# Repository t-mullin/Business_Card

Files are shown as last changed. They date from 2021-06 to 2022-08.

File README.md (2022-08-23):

# STG Business Card

## UPDATE!  
I am working on some updates to the STG Business Card project.
1. Adding additional options of form-factor/materials.
2. Adding Through-Hole and SMD versions.
3. Reworking of the project structure.

## Motive
The motive behind this project is to provide to prospective employers an example of my pcb work in a form factor that is easy for them to carry around. I came up with the idea of putting a simple Stepped Tone Generator onto a PCB the size of a business card after watching a video from [Look Mum No Computer](https://www.youtube.com/watch?v=4lK7kdgK7dI), where he builds an Atari Punk Console (Stepped Tone Generator). 

## PCB Design
Using the same instructables guide from [BrownDogGadgets](https://www.instructables.com/Build-an-Atari-Punk-circuit-on-a-breadboard/), I used KiCad to draw up the schematic and designed a PCB to go with it. The PCB is a 2-layer design with through-hole components. Below are pictures of the 3D model and the PCB layout in KiCad.   

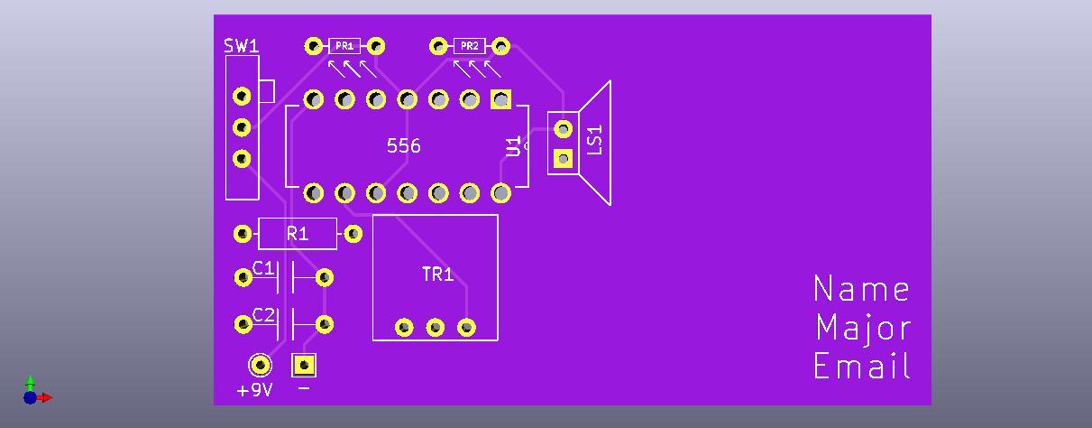
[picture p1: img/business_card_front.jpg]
Business Card Front


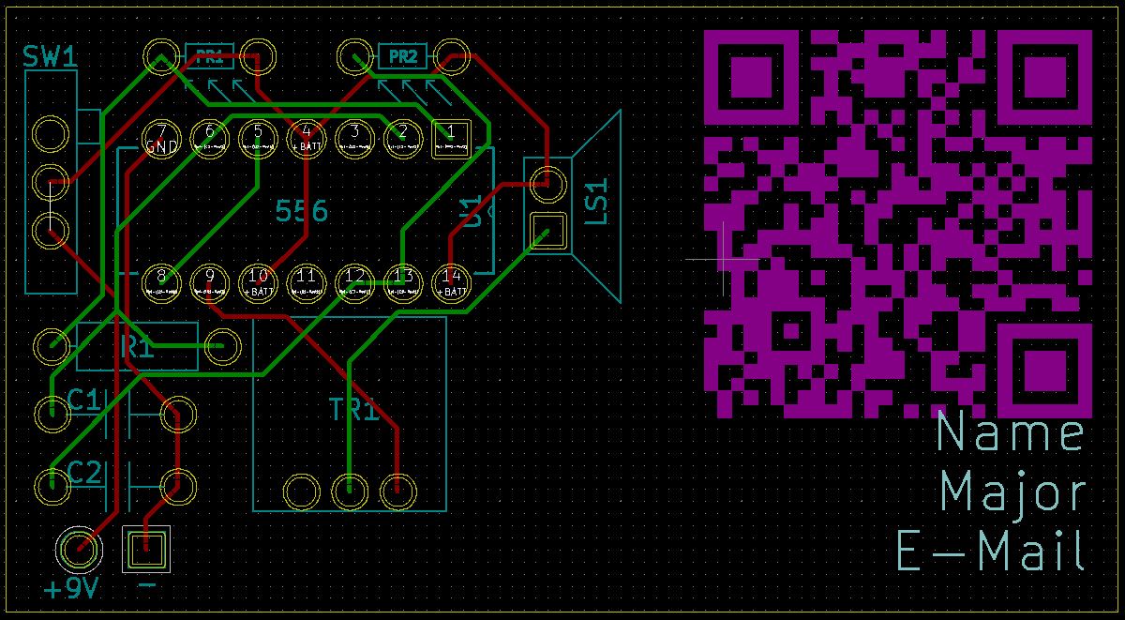
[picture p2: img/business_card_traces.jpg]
Business Card Traces


## Bill of Materials
| Description | Ref | Component Value | Part # | Link |
| --- | --- | --- | --- | --- |
| Resistor | R1 | 1K | CFR-25JB-52-1K | [Digi-key](https://www.digikey.com/en/products/detail/yageo/CFR-25JB-52-1K/96) |
| Capacitor | C1, C2 | 0.22u | K224M20X7RF53H5 | [Mouser](https://www.mouser.com/ProductDetail/Vishay-BC-Components/K224M20X7RF53H5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) |
| 556 Timer | U1 | 556 | NE556N | [Mouser](https://www.mouser.com/ProductDetail/Texas-Instruments/NE556N?qs=gb35HGp1gQKUkn%252B6zgU6RA%3D%3D) |
| IC Socket | U1 | 14 Pin DIP | ICS-314-T | [Digi-Key](https://www.digikey.com/en/products/detail/adam-tech/ICS-314-T/9832866)
| Photoresistor | PR1, PR2 | 1k - 10k | 161 | [Adafruit](https://www.adafruit.com/product/161) |
| Trimmer Resistor | TR1 | 5k | 3386T | [Mouser](https://www.mouser.com/ProductDetail/Bourns/3386T-1-502LF?qs=0VqvB9JLnIv4eQGVkebFKQ%3D%3D) | 
| Speaker | LS1 | 8 ohm | 1890 | [Adafruit](https://www.adafruit.com/product/1890) |
| Switch | SW1 | SPDT | 805 | [Adafruit](https://www.adafruit.com/product/805) |
| 9V Battery Clip  | Batt/9V  | 9V | 235 | [Mouser](https://www.mouser.com/ProductDetail/Keystone-Electronics/235?qs=w4ABFRoM%2FL90W35cnqrFmA%3D%3D) |

## Assembly Order
For ease of assembly, start with the lower profile components and work up to the higher profile components.

I assembled the circuit in this order: 
1. Resistor and Photoresistors 
2. IC Socket
3. Capacitors
4. Switch
5. Potentiometer
6. Speaker and Battery Clip
7. IC

## Assembled Circuit
Below is an assembled STG circuit. A demo of the circuit can be found here: [STG Demo](https://youtu.be/Ry3vZIr_BqI)
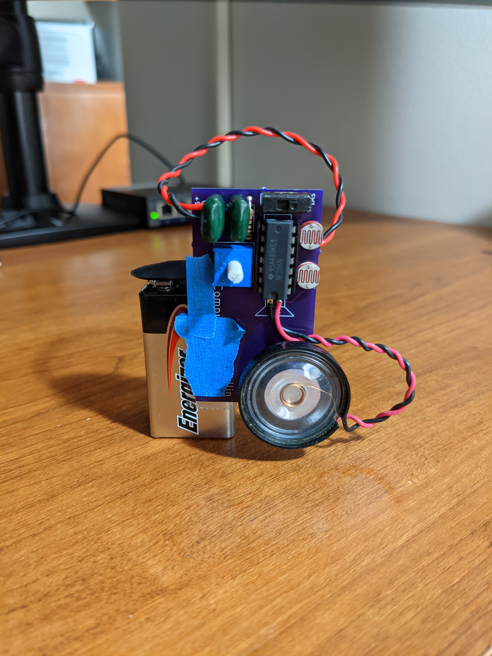
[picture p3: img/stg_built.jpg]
Assembled STG


## Postmortem
Overall, I happy with the final product. ~~However, I may add an additional PCB, to this project, that swaps out the photoresistors for potentiometers.~~ Alternate version has been added. However, it is untested.
For the alternate design, below are the parts that have changed.
- TR2 & TR3 = 500k ohms
- C1 & C2 = 0.01 uF

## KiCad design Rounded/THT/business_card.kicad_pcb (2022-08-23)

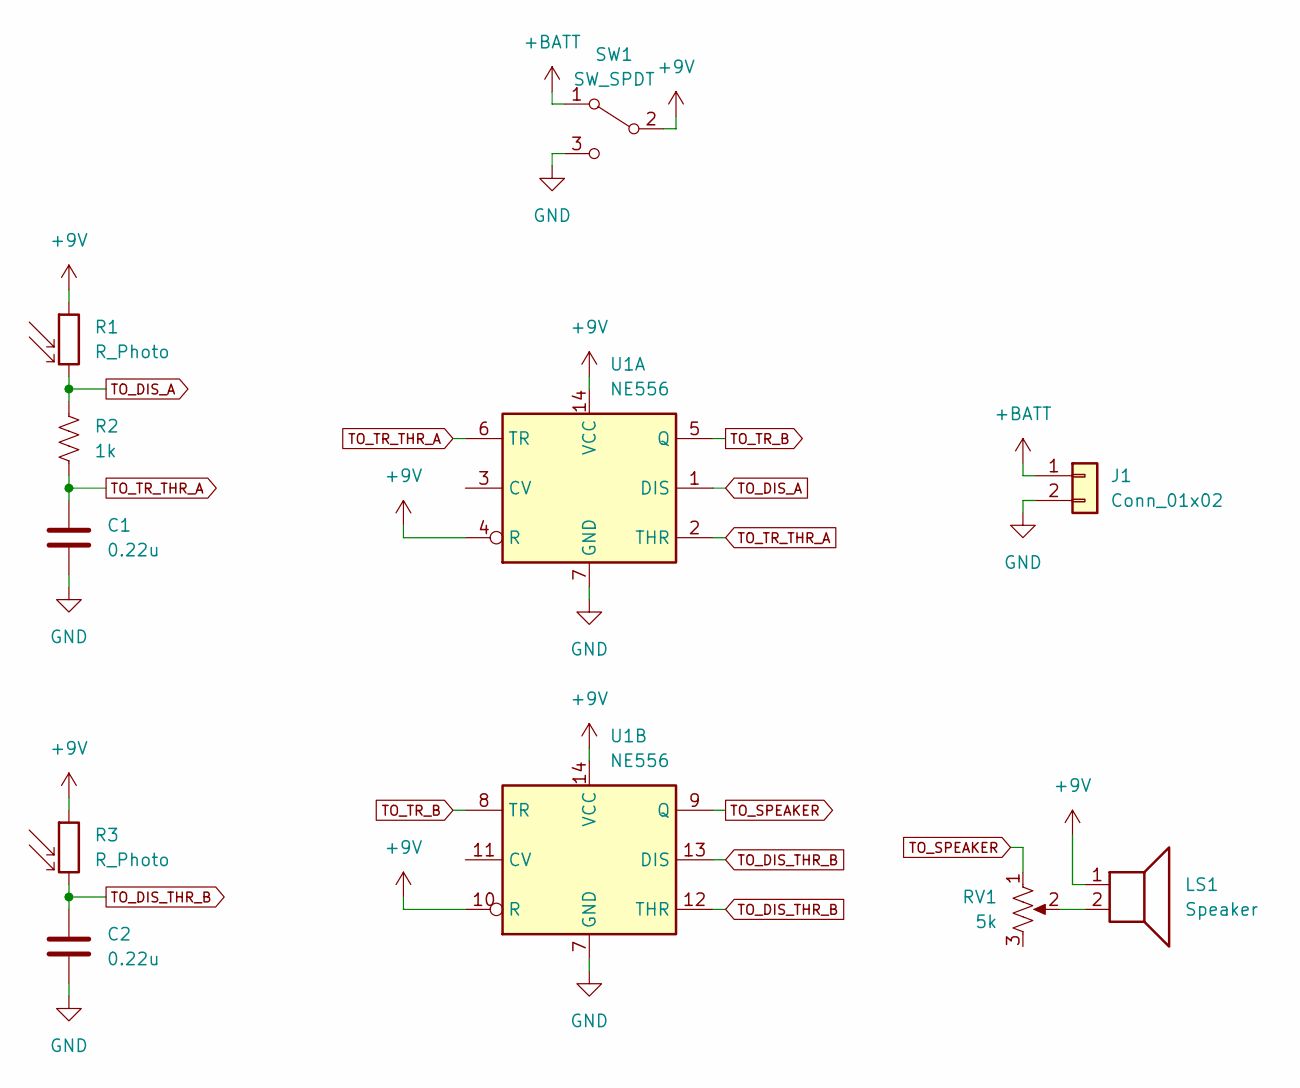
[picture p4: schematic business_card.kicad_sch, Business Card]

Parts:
C1, C2: 0.22u; C_Disc_D7.0mm_W2.5mm_P5.00mm
J1: Conn_01x02; PinSocket_1x02_P2.54mm_Vertical
LS1: Speaker; PinSocket_1x02_P2.54mm_Vertical
R1, R3: R_Photo; R_Axial_DIN0207_L6.3mm_D2.5mm_P5.08mm_Vertical
R2: 1k; R_Axial_DIN0207_L6.3mm_D2.5mm_P7.62mm_Horizontal
RV1: 5k; Potentiometer_Bourns_3386C_Horizontal
SW1: SW_SPDT; PinSocket_1x03_P2.54mm_Vertical
U1: NE556; DIP-14_W7.62mm_Socket_LongPads

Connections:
+9V: LS1.1, R1.1, R3.1, SW1.2 (B), U1.4 (R), U1.10 (R), U1.14 (VCC)
+BATT: J1.1, SW1.1 (A)
GND: C1.2, C2.2, J1.2, SW1.3 (C), U1.7 (GND)
unnamed: LS1.2, RV1.2
TO_DIS_A: R1.2, R2.1, U1.1 (DIS)
TO_DIS_THR_B: C2.1, R3.2, U1.12 (THR), U1.13 (DIS)
TO_SPEAKER: RV1.1, U1.9 (Q)
TO_TR_B: U1.5 (Q), U1.8 (TR)
TO_TR_THR_A: C1.1, R2.2, U1.2 (THR), U1.6 (TR)

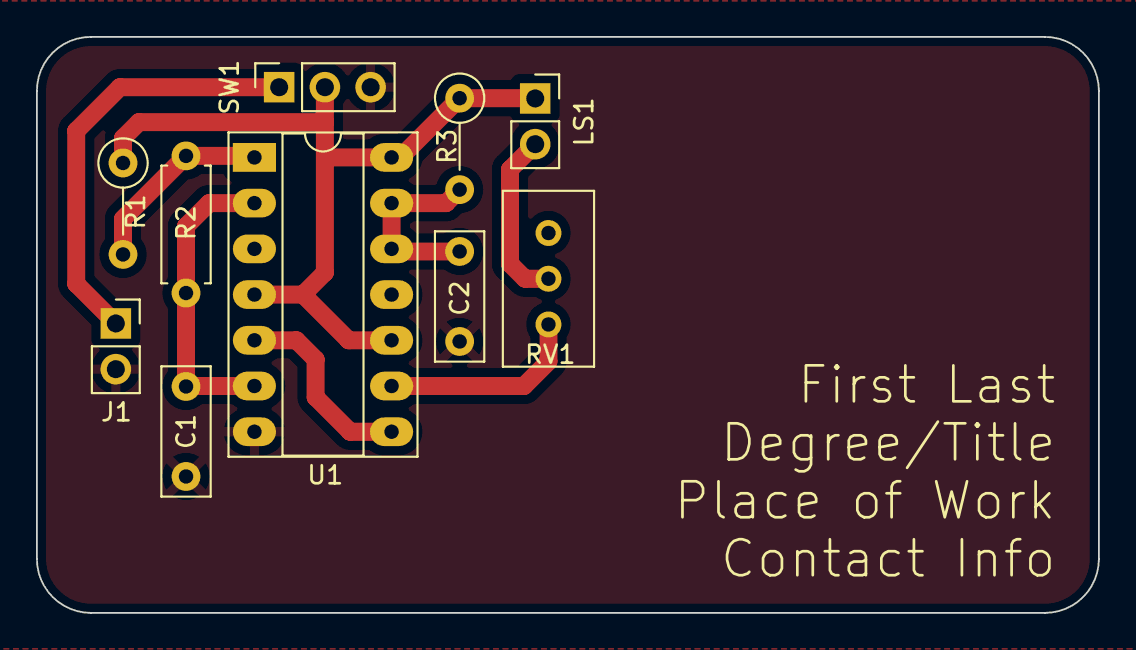
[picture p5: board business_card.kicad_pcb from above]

Board: 2 copper layers, 59.0 x 32.0 mm, 10 parts (0 on the bottom side), 9 nets.

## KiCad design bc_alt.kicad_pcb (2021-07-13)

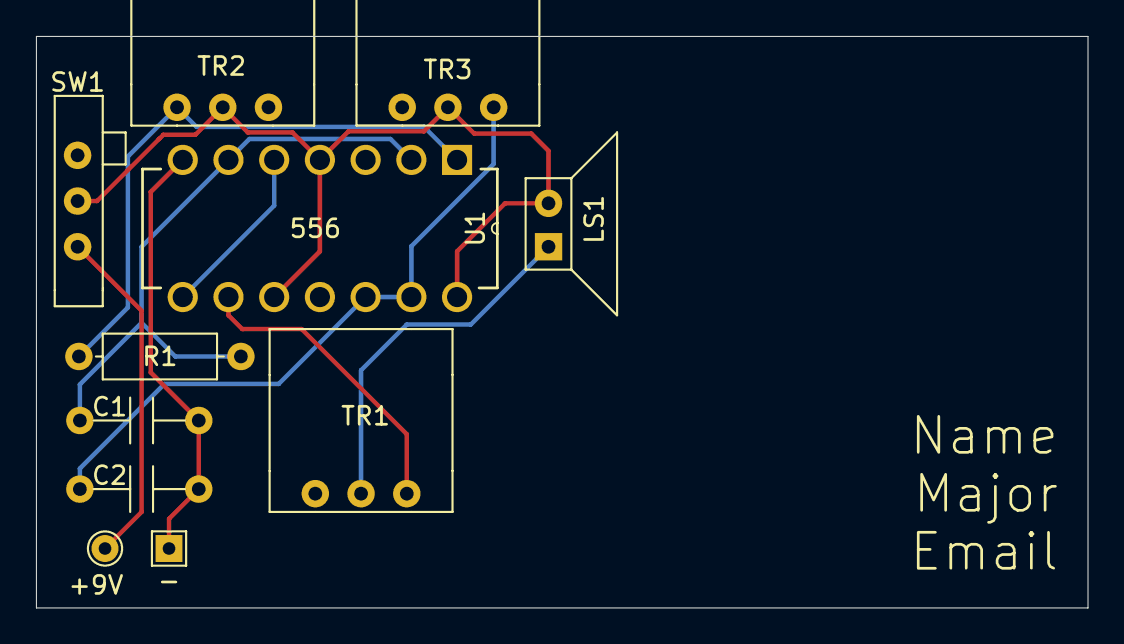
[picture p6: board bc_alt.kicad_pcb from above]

Board: 2 copper layers, 58.4 x 31.8 mm, 11 parts (0 on the bottom side), 8 nets.

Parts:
+9V: TestPoint_THTPad_D1.5mm_Drill0.7mm
-: TestPoint_THTPad_1.5x1.5mm_Drill0.7mm
C1, C2: c_gen
LS1: Speaker; speaker_gen
R1: r_gen
SW1: slide_switch_general
TR1, TR2, TR3: trimpot_gen
U1: NE556N_gen; DIP254P762X508-14

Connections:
+BATT: +9V.1, LS1.1, SW1.2, SW1.3, TR2.2, TR3.2, U1.4, U1.10, U1.14
GND: -.1, C1.2, C2.2, U1.7
unnamed: C1.1, R1.2, U1.2, U1.6
unnamed: C2.1, TR3.3, U1.12, U1.13
unnamed: LS1.2, TR1.2
unnamed: R1.1, TR2.1, U1.1
unnamed: TR1.3, U1.9
unnamed: U1.5, U1.8

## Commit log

2021-06-22 Added Bill of Materials to the README.
2021-06-22 added KiCad project files
    [business_card.kicad_pcb, business_card.sch]
2021-06-22 added image to README and moved battery silkscreen lables
    [business_card.kicad_pcb]
2021-06-22 modified the qr code url
    [business_card.kicad_pcb]
2021-07-06 Switched out Capacitor part and supplier.
2021-07-06 changed out the traces img
2021-07-06 fixed unintended wrapping in the BOM table
2021-07-13 added alt version that has trim pots instead of photoresistors
    [bc_alt.kicad_pcb, bc_alt.sch]
2022-08-23 major reorg
    [bc_alt.kicad_pcb, bc_alt.sch, business_card.kicad_pcb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]
2022-08-23 added a rounded corners version
    [business_card.kicad_pcb, business_card.kicad_sch]
